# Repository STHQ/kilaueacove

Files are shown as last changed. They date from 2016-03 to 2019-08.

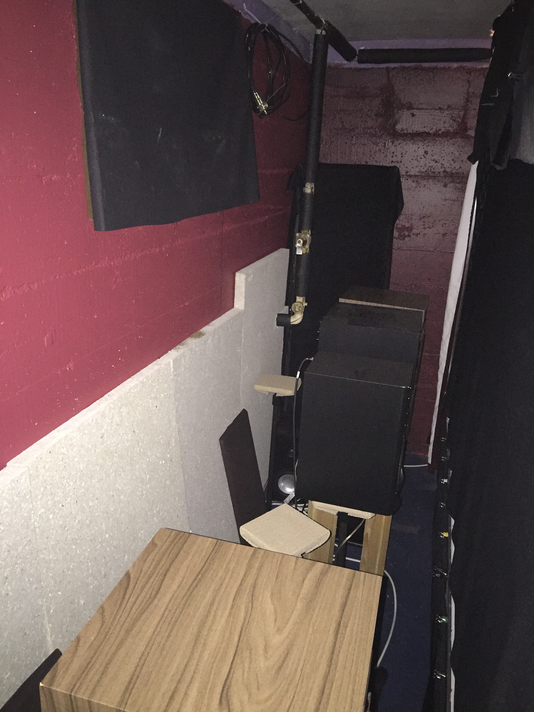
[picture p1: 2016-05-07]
screeningroom/drawings/Screening Room Photos/screening-room-behind-screen.jpg

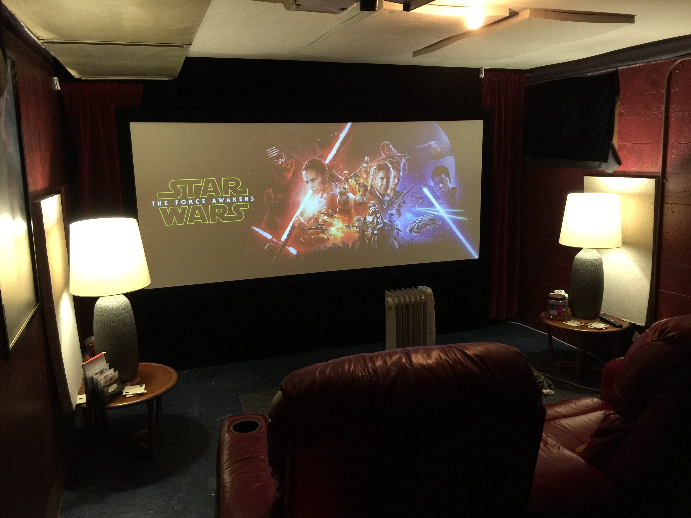
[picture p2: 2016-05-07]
screeningroom/drawings/Screening Room Photos/screening-room-forward.jpg

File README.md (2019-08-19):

# Kilauea Cove

> [As featured on Critiki!](https://news.critiki.com/2017/04/25/how-to-build-a-volcano-raspberry-pi-style/) Thanks, Humuhumu!

This repository relates to my screening room (home theater), the bar area, and the “tiki took,” just outside the screening room’s door, where there is a drinks cart, and shelves with tiki mugs and other barware. Collectively, this is **[Kilauea Cove](https://critiki.com/location/kilauea-cove-seattle-1005/)**.

The purpose is to collect all of my code, wiring diagrams, graphical elements, and setup instructions for the lighting, effects, and other electronics in the space — not only for my own use (if/when we move and I have to piece it back together again), but as a reference for anyone else who plans to build interactive lights and effects for a small space.

I did a [full write-up on my Vixen Labs website](https://vixenlabs.com/2017/02/18/kilauea-cove-raspberry-pi-active-volcano/), with information about how I built the whole Cove space. I have also posted work-in-progress photos and commentary to a thread on [Tiki Central](http://www.tikiroom.com/tikicentral/bb/viewtopic.php?topic=51211&forum=20&25), though that is a bit out of date.

As I update further versions of this project, you'll find posts under the [Kilauea Cove](https://vixenlabs.com/project/kilauea-cove/) tag on Vixen Labs.

## Wiki

[Visit the wiki](https://github.com/bobtiki/kilaueacove/wiki) for more details on construction, programming, and decor!

## The Name

**Q:** Why “Kilauea Cove”?

**A:** The most direct references are [Kilauea](https://en.wikipedia.org/wiki/Kīlauea), the most active volcano in the Hawaiian Islands, which ties in to what I hope will be a very active Volcano Show. *Cove* can be defined as “[a recessed place](http://www.merriam-webster.com/dictionary/cove),” which describes the Tiki Nook very well. Of course, the alternate water-related meaning of *cove*, and the reference to [one of my favorite surf rock bands](http://www.kilaueas.de), only add to the enjoyment.

Plus, y’know, alliteration is pretty fun.

**Q:** Wasn't this called “Lava Lounge” before?

**A:** Yes. However, the old name, “Lava Lounge,” unintentionally duplicated the name of [a Seattle bar](https://critiki.com/location/lava-lounge-seattle-173/). To reduce possible confusion (since I am *also* in Seattle), and to give my space a unique\* name globally, *Kilauea Cove* is the new name.

<sub>\*The only other Kilauea Cove I could find, by searching online, is the name of a pair of water slides at [Big Surf Water Park](http://bigsurffun.com/rides/) in Tempe, AZ.</sub>

## Licenses

The Kilauea Cove project is Copyright © 2016–2018 Mark N. Boszko.

This repository contains clones of software developed by other people, when necessary to the operation of my systems. Their licenses continue to apply.

Unless otherwise stated, all content authored by me, Mark Boszko, and contained in this repository, is covered under one of two permissive licenses — one for software, and one for other elements.

### Software

Since [Creative Commons recommends against applying their licenses to software](https://creativecommons.org/faq/#can-i-apply-a-creative-commons-license-to-software), my code is available under the **MIT license**. This includes code for running on Raspberry Pi and Arduino. Please see [LICENSE.txt](LICENSE.txt) for the full license text, but the rough version is: do what you like with it, but please credit me if you use my code.

### Graphics

Kilauea Cove™ logos and insignia are © 2016–2018 Mark Boszko, and are presented for illustrative purposes. These graphics may not be used without permission.

### Other Elements

All other elements (unless otherwise noted), including documentation, and diagrams, are licensed under **CC-BY-4.0**.

<br /><span xmlns:dct="http://purl.org/dc/terms/" property="dct:title">Kilauea Cove</span> by <a xmlns:cc="http://creativecommons.org/ns#" href="http://stationinthemetro.com/tag/lava-lounge" property="cc:attributionName" rel="cc:attributionURL">Mark N. Boszko</a> is licensed under a <a rel="license" href="http://creativecommons.org/licenses/by/4.0/">Creative Commons Attribution 4.0 International License</a>.

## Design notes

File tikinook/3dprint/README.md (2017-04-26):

# 3D Printer Files

## Kilauea Smoke Mount

v04

This is a 3D-printable mount for a smoke generator, made to fit inside a tiki mug. The mount was designed in [OpenSCAD](http://www.openscad.org), and included here are the current OpenSCAD file (for editing) and Stereo Lithography (STL) file for printing, as well as an image preview render.

### Compatibility

- [Seuthe #5 smoke generator](http://www.gaugemaster.com/item_details.asp?code=SEUTHE%20NO5&r=1) (for model trains / buildings, 4.5-6V, 260mA)
- Trader Sam's Enchanted Tiki Bar, [Krakatoa mug](http://www.ooga-mooga.com/cgi-bin/all/mug.cgi?mode=view&mug_id=7021)
- [NeoPixel Ring - 24 x 5050 RGB LED with Integrated Drivers](https://www.adafruit.com/product/1586)

### Concept
Mount to hold the smoke generator upright inside the base of the tiki mug, with a NeoPixel (LED) ring mount at the top.

### TODO

- Add a ring at the top that I can mount the NeoPixels LED ring to directly

### Version History

- v04
    - Remove “smoke collection hat” that did more harm than good.
    - Left the stems that supported the hat, as a makeshift handle to seat/remove the stand inside the mug.
- v03
    - Added a second small ring to hold the smoke generator more securely and keep it from tipping.
- v02
    - Added smoke “hat”. The idea was to spread the smoke out over a wider area to give the illusion of a larger smoke source. This did not work.
- v01
    - Base ring and small ring for generator only.

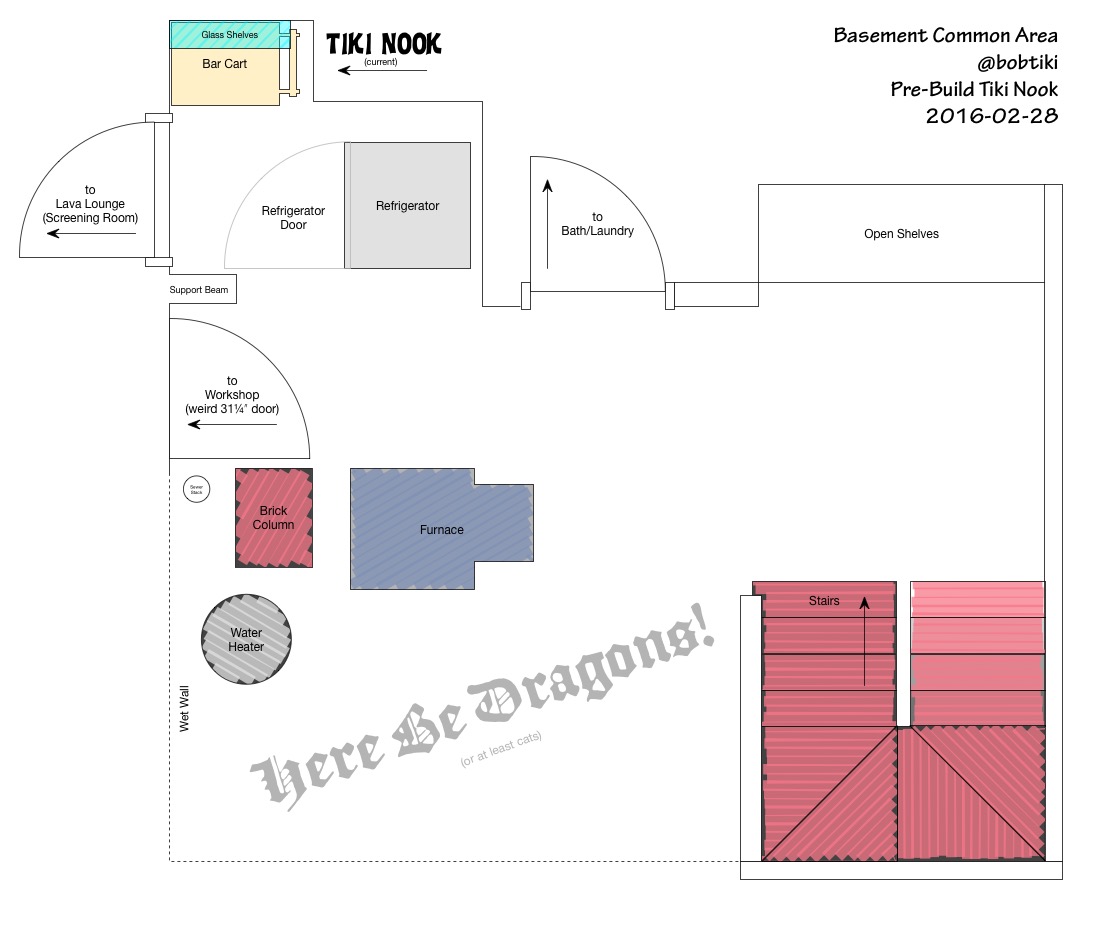
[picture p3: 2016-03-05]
tikinook/drawings/Tiki Nook Overhead.jpg

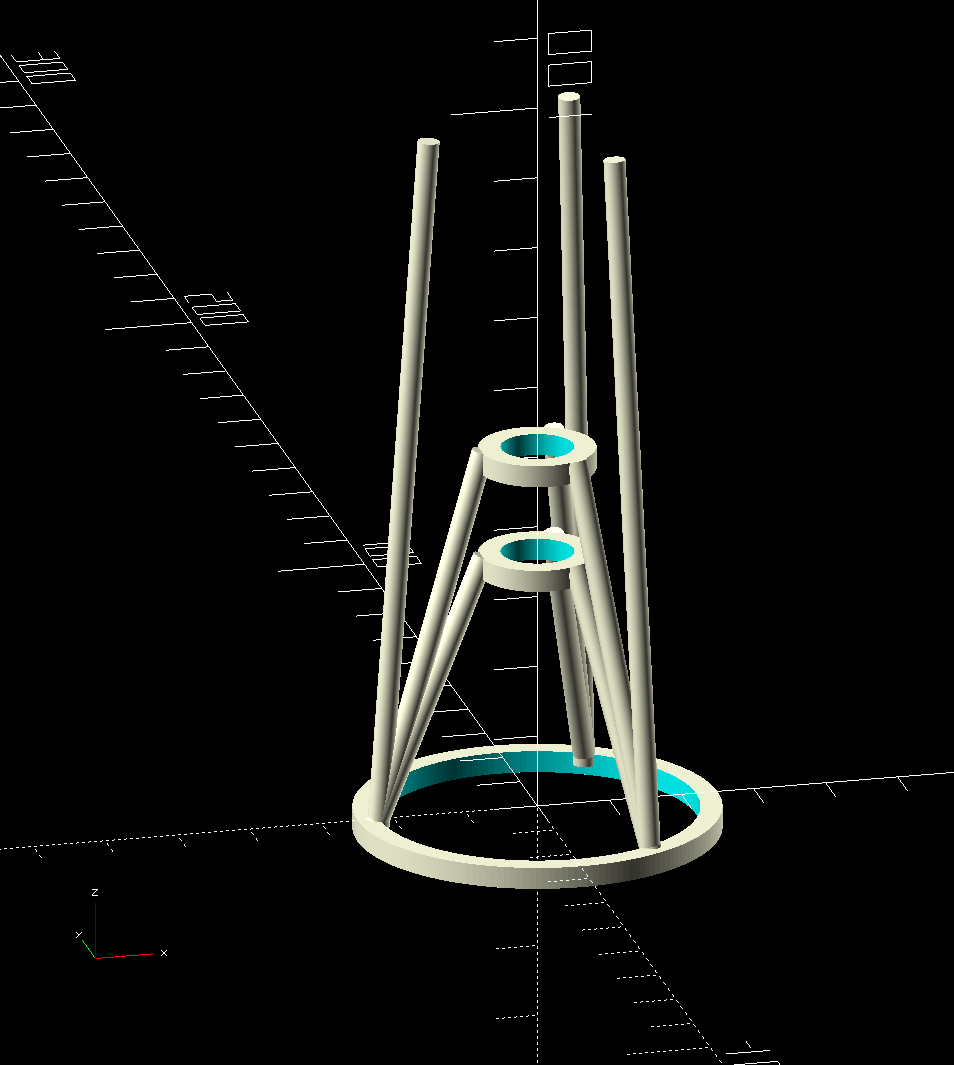
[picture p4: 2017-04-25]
tikinook/3dprint/kilauea-smoke-mount-preview.png

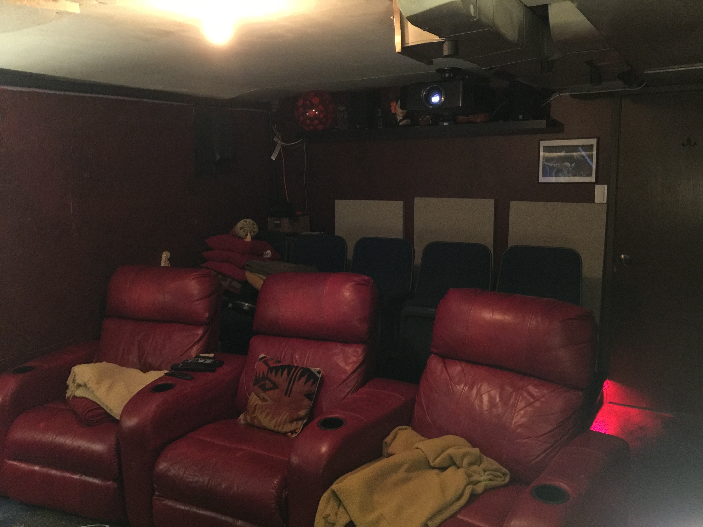
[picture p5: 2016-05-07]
screeningroom/drawings/Screening Room Photos/screening-room-reverse.jpg

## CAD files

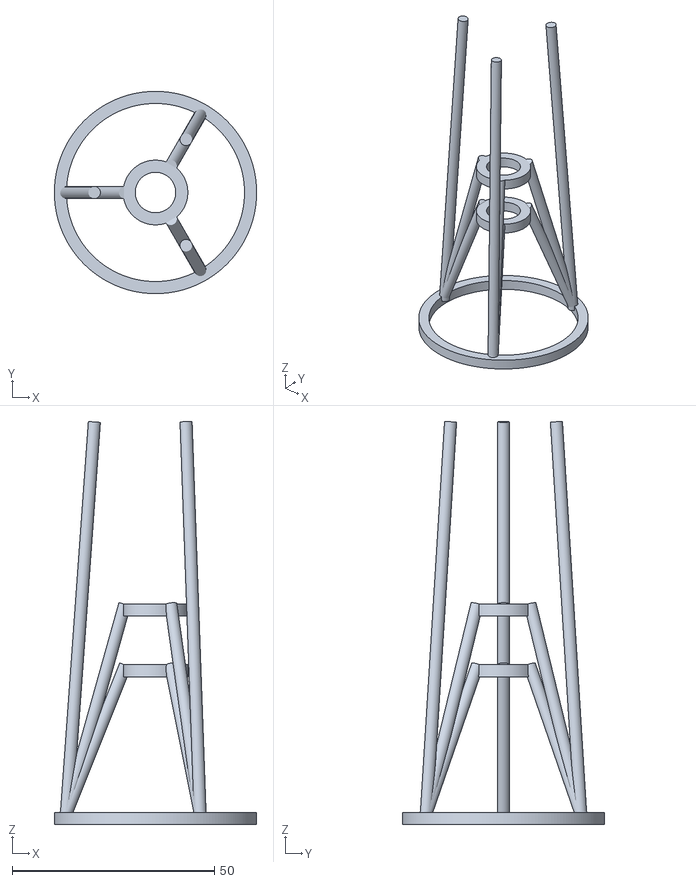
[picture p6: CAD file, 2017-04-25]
tikinook/3dprint/kilauea-smoke-mount.stl
50.0 x 50.0 x 99.6

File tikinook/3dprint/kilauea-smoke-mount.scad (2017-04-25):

// Kilauea Cove
// (c) 2016 Mark Boszko
// Mount for Seuthe smoke generator inside volcano
// v04

// Compatibility:
// - Seuthe #5 smoke generator (for model trains / buildings, 4.5-6V, 260mA)
// - Trader Sam's Enchanted Tiki Bar - Krakatoa mug

// Concept:
// Mount to hold the smoke generator upright in the base of the tiki mug,
// with a separate ring-light mount and smoke collection cone that will(?)
// make the amount of smoke look larger by creating a cylinder of smoke.

// TODO:
// - Add a ring at the top that I can mount the NeoPixels LED ring to directly

// Resolution
// REZ: $fn fragments per circle
//     default: 0 (draft); export: 100 or more
REZ = 180;

// Smoke generator dimensions
gen_diameter = 10.0;  // in mm
gen_height = 45.0;

gen_distance = 50.0;  // distance from base to holder ring
gen_distance_2 = 35.0;
base_diameter = 50.0;

thickness = 3.0;
stems_count = 3;

hat_distance = gen_height + gen_distance + thickness;  // distance from base to smoke collection hat
hat_diameter = 30.0;  // in mm
hat_slope = 2.0;      // ratio of radius to height, x:1


module base() {
    
    base_inner_diameter = base_diameter - thickness * 2;
    
    // the ring itself
    translate([0, 0, - thickness / 2]) difference() {
        cylinder($fn = REZ, h = thickness, d = base_diameter, center = true);
        cylinder($fn = REZ, h = thickness, d = base_inner_diameter, center = true);
    }

}


module gen_ring(height) {
    
    ring_outer_diameter = gen_diameter + thickness * 2;
    
    // the ring itself
    translate([0, 0, height]) difference() {
        cylinder($fn = REZ, h = thickness, d = ring_outer_diameter, center = true);
        cylinder($fn = REZ, h = thickness, d = gen_diameter, center = true);
    }

}


module stem(height) {
    ring_radius = (gen_diameter + thickness * 2) / 2;
    base_radius = (base_diameter - thickness * 2) / 2;
    stem_triangle_base = base_radius - ring_radius;
    stem_triangle_hypotenuse = sqrt(stem_triangle_base * stem_triangle_base + height * height);
    stem_length = stem_triangle_hypotenuse + thickness * 2;
    stem_angle = 90.0 - asin( height / stem_triangle_hypotenuse );
    translate([-base_radius, 0, 0]) rotate([0, stem_angle, 0]) translate([0, 0, -thickness * 1.5]) cylinder($fn = REZ, h = stem_length, d = thickness, center = false);
}

module stems(height) {
    difference() {
        for (i = [1:stems_count]) {
            angle_delta = 360.0 / stems_count;
            angle = i * angle_delta;
            rotate([0, 0, angle]) stem(height);
        }
        // cleanup where the stems stick out of the rings
        translate([0, 0, height + thickness / 2]) cylinder($fn = REZ, h = thickness * 2, d = gen_diameter, center = true);
        translate([0, 0, -thickness * 1.5]) cylinder($fn = REZ, h = thickness * 2, d = base_diameter + thickness, center = true);
    }   
}

// TODO: Convert this into a printed ring to secure the NeoPixel LED ring to
module hat() {
    height = hat_diameter / 2.0 / hat_slope;
    difference() {
        translate([0, 0, hat_distance]) cylinder(h=height, d1=hat_diameter, d2=0, center=true);translate([0, 0, hat_distance - thickness / 3]) cylinder(h=height, d1=hat_diameter, d2=0, center=true);
    }
}

// TODO: modify this for the hat
module hat_stem() {
    hat_radius = (hat_diameter) / 2;
    base_radius = (base_diameter - thickness * 2) / 2;
    stem_triangle_base = base_radius - hat_radius;
    stem_triangle_hypotenuse = sqrt(stem_triangle_base * stem_triangle_base + hat_distance * hat_distance);
    stem_length = stem_triangle_hypotenuse + thickness;
    stem_angle = 90.0 - asin( hat_distance / stem_triangle_hypotenuse );
    translate([-base_radius, 0, 0]) rotate([0, stem_angle, 0]) translate([0, 0, -thickness * 1.5]) cylinder($fn = REZ, h = stem_length, d = thickness, center = false);
}

module hat_stems() {
    difference() {
        for (i = [1:stems_count]) {
            angle_delta = 360.0 / stems_count;
            angle = i * angle_delta;
            rotate([0, 0, angle]) hat_stem();
        }
        // cleanup where the stems stick out of the rings
        translate([0, 0, gen_distance + thickness / 2]) cylinder($fn = REZ, h = thickness * 2, d = gen_diameter, center = true);
        translate([0, 0, -thickness * 1.5]) cylinder($fn = REZ, h = thickness * 2, d = base_diameter + thickness, center = true);
    }
    
}


module assembly() {
    union() {
        base();
        gen_ring(gen_distance);
        stems(gen_distance);
        gen_ring(gen_distance_2);
        stems(gen_distance_2 );
    }
}

assembly();
// removed hat() because it blocks the smoke too much,
//     but keeping the stems, because they're at least handy for picking up
//     the stand from the narrow inside of the mug
hat_stems();

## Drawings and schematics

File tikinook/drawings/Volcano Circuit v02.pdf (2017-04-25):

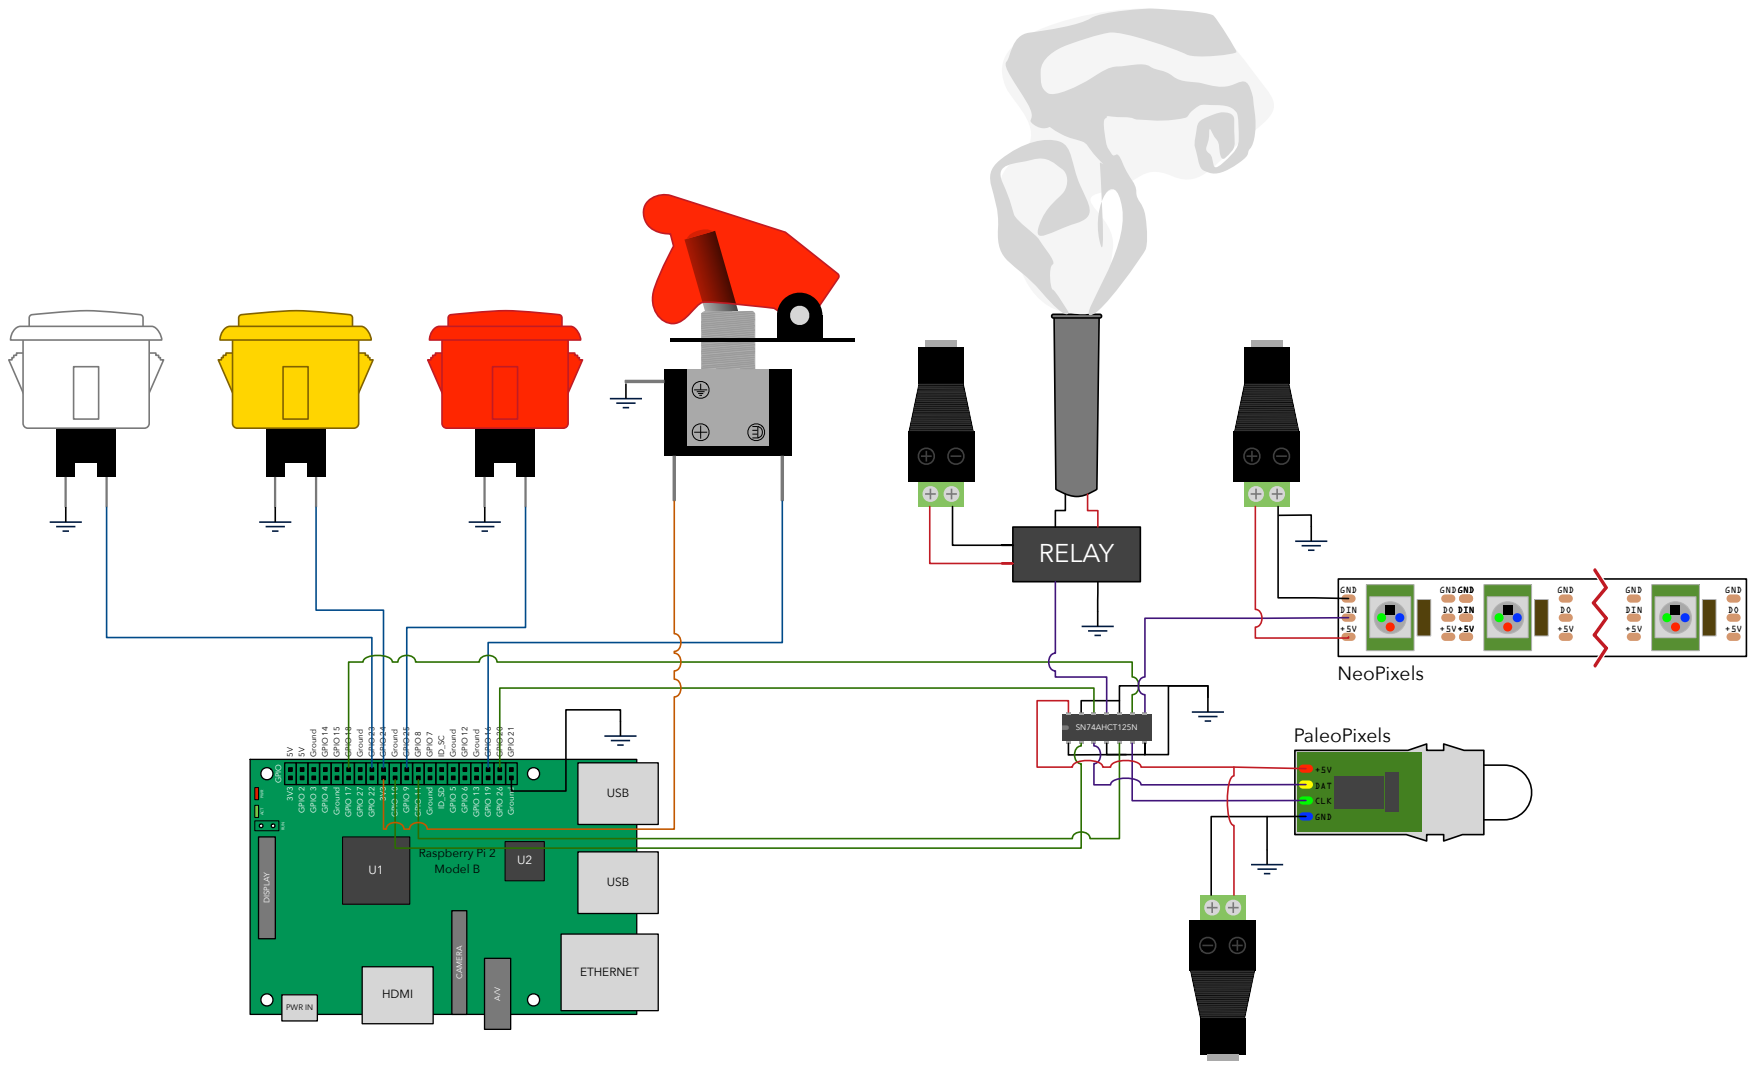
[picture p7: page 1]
ETHERNET; USB; CAMERA; DISPLAY; RUN; ACT PWR; GPIO; GPIO 3; GPIO 11; Ground; GPIO 19; GPIO 2; GPIO 26; GPIO 9; GPIO 17; GPIO 27; GPIO 10; GPIO 4; GPIO 5; GPIO 6; GPIO 22; GPIO 13; GPIO 14; GPIO 15; GPIO 18; GPIO 23; GPIO 24; GPIO 25; GPIO 8; GPIO 7; GPIO 12; GPIO 16; GPIO 20; GPIO 21; Raspberry Pi 2 Model B; GND; DIN; NeoPixels; DAT; CLK; PaleoPixels SN74AHCT125N; RELAY

HDMI PWR IN

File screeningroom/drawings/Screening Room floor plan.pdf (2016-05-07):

L | R C | S

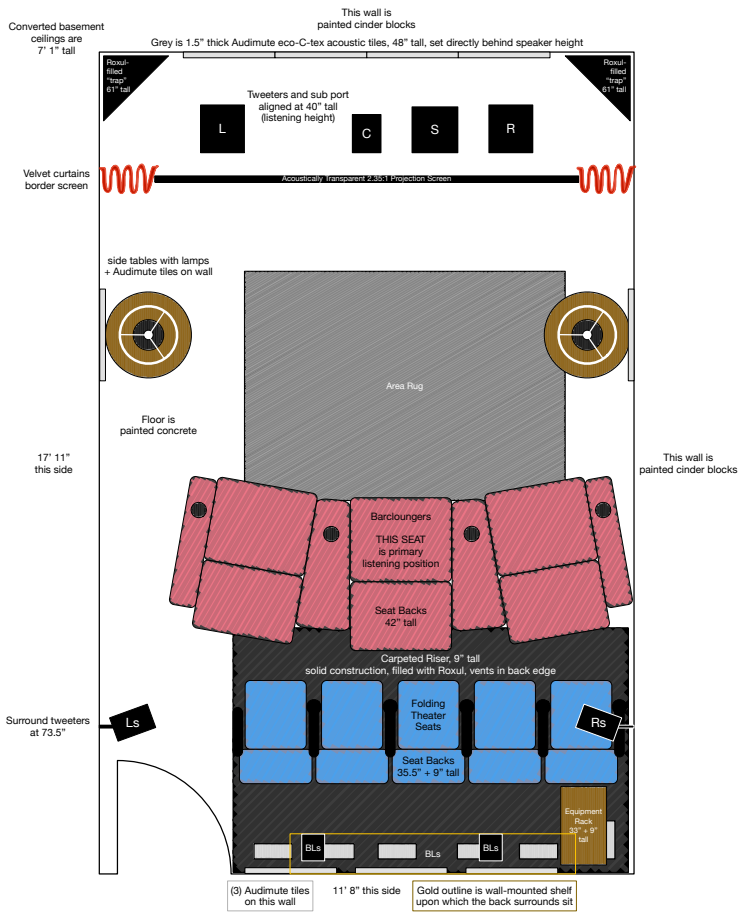
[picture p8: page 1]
Area Rug; Folding Theater Seats; Seat Backs 35.5” + 9” tall; Equipment Rack 33” + 9” tall; Roxul- filled “trap” 61” tall; 11’ 8” this side; 17’ 11” this side; Velvet curtains border screen; Converted basement ceilings are 7’ 1” tall; Floor is painted concrete; Barcloungers; THIS SEAT is primary listening position; Seat Backs 42” tall; Surround tweeters; BLs

This wall is
painted cinder blocks

Grey is 1.5” thick Audimute eco-C-tex acoustic tiles, 48” tall, set directly behind speaker height

Tweeters and sub port
aligned at 40” tall
(listening height)

Acoustically Transparent 2.35:1 Projection Screen

side tables with lamps
+ Audimute tiles on wall

Carpeted Riser, 9” tall

solid construction, filled with Roxul, vents in back edge

(3) Audimute tiles
on this wall

Gold outline is wall-mounted shelf
upon which the back surrounds sit

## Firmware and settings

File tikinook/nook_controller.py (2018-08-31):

#!/usr/bin/env python3
# -*- coding: UTF-8 -*-
"""
Code specific to controlling the lights and other display events
in the tiki nook for Kilauea Cove.

Must be run from the current directory, else the animation will not load, as:
    sudo python nook_controller.py

Author: Mark Boszko (boszko+kilaueacove@gmail.com)

License:
Licensed under The MIT License (MIT). Please see LICENSE.txt for full text
of the license.

Version History:
- 2.0.0 - 2018-08-13 - Upgrades to show, and OSC for communication
- 0.2.0 - 2016-08-07 - Add the 3 button NeoPixels + the 24 ring NeoPixels
                       Fixed the red toggle detection + volcano show restriction
- 0.1.0 - 2016-05-07 - Started development
"""

import argparse
import numpy
import RPi.GPIO as GPIO
import time
import threading

from pythonosc import dispatcher
from pythonosc import osc_server

import neopixel
import paleopixel
from superpixel import *

# ------------------------------
# GPIO setup
# ------------------------------

# Identify GPIO pins

BUTTON_WHITE_IN = 23
BUTTON_AMBER_IN = 24
BUTTON_RED_IN = 25
TOGGLE_RED_IN = 16
SMOKE_CONTROL = 21

# Set up GPIO pins

GPIO.setmode(GPIO.BCM)

GPIO.setup(BUTTON_WHITE_IN, GPIO.IN, pull_up_down=GPIO.PUD_UP)
GPIO.setup(BUTTON_AMBER_IN, GPIO.IN, pull_up_down=GPIO.PUD_UP)
GPIO.setup(BUTTON_RED_IN, GPIO.IN, pull_up_down=GPIO.PUD_UP)
GPIO.setup(TOGGLE_RED_IN, GPIO.IN, pull_up_down=GPIO.PUD_DOWN)
GPIO.setup(SMOKE_CONTROL, GPIO.OUT)

# ------------------------------
# LED setup
# ------------------------------

# Set up the super_strand

# My LED strip configurations (for test):
WHITE_LED = 0  # These are the LEDs inside the buttons
AMBER_LED = 1
RED_LED = 2
NEOPIXEL_COUNT = 271  # Number of NeoPixels in the super_strand
NEOPIXEL_PIN = 18  # GPIO pin connected to the pixels (must support PWM!)
PALEOPIXEL_COUNT = 50  # Number of PaleoPixels in the super_strand

# Create pixel strands with appropriate configuration.
neopixel_strand = neopixel.Adafruit_NeoPixel(NEOPIXEL_COUNT, NEOPIXEL_PIN)
paleopixel_strand = paleopixel.PaleoPixel(PALEOPIXEL_COUNT)

# Combine them into one SuperPixel super_strand
super_strand = SuperPixel(neopixel_strand, paleopixel_strand)

# Intialize the SuperPixel super_strand (must be called once, before other
# functions, if the SuperPixel super_strand contains any NeoPixel sub-strands)
super_strand.begin()

# Set up grid segments
grid = PixelGrid(super_strand, (311, 10), (310, -10), (291, 10), (290, -10), (271, 10), (246, -41), (165, 41), (164, -41),
                 (83, 41), (82, -41), (3, 39))
button_grid = PixelGrid(super_strand, (0, 3))
rattan_grid = PixelGrid(super_strand, (311, 10), (310, -10), (291, 10), (290, -10), (271, 10))
shelf_back_grid = PixelGrid(super_strand, (165, 41), (83, 41), (3, 39))
shelf_front_grid = PixelGrid(super_strand, (246, -41), (164, -41), (82, -41))
ring_grid = PixelGrid(super_strand, (247, 24))


# ------------------------------
# Eruption animation setup
# ------------------------------

# load the animation
volcano_animation = PixelPlayer(rattan_grid, '/home/pi/kilaueacove/tikinook/animation/volcano-v05-16x16.mov')


# ------------------------------
# Globals
# ------------------------------

# Make these globals so threaded button functions can address it
global WHITE_TIMEOUT
WHITE_TIMEOUT = None
# Length in seconds
WHITE_TIMEOUT_LENGTH = 300

global IS_TOGGLE
IS_TOGGLE = False


# ------------------------------
# Callback methods
# ------------------------------

# FIXME: animation functions need to know when another function has been called
#        and cancel any further animation in the current function.

# TODO: smooth transitions between animation functions

# Set up our GPIO callbacks
def button_white(channel='default'):
    """Turns on the bottom row of LEDs white, for mixing drinks.
    
    Times out based on the value in WHITE_TIMEOUT_LENGTH (seconds)
    """
    print("button_white()")
    print("channel: ", channel)

    # Cancel the timer for the white light
    global WHITE_TIMEOUT
    if (WHITE_TIMEOUT is not None):
        WHITE_TIMEOUT.cancel()

    # Set all row colors the same as button_amber(), except
    # get the row underneath the bottom shelf, and show white
    button_grid.setRowColorRGB(0, 16, 16, 16)
    button_grid.setPixelColorRGB(WHITE_LED, 0, 64, 64, 64)
    button_grid.show()
    ring_grid.setRowColorRGB(0, 0, 0, 0)
    ring_grid.show()
    shelf_back_grid.setRowColorRGB(2, 255, 160, 64)  # a more "natural" white
    shelf_back_grid.show()

    # Start a timer to go back to amber after WHITE_TIMEOUT_LENGTH
    WHITE_TIMEOUT = threading.Timer(WHITE_TIMEOUT_LENGTH, button_amber, ['WHITE_TIMEOUT'])
    WHITE_TIMEOUT.start()


def button_amber(channel='default'):
    """Default idle mode.
    
    TODO: subtle animation
    """
    print("button_amber()")
    print("channel: ", channel)

    # Cancel the timer for the white light
    global WHITE_TIMEOUT
    if (WHITE_TIMEOUT is not None):
        WHITE_TIMEOUT.cancel()

    # Set pretty colors
    button_grid.setRowColorRGB(0, 16, 16, 16)
    button_grid.setPixelColorRGB(AMBER_LED, 0, 64, 64, 64)
    button_grid.show()
    ring_grid.setRowColorRGB(0, 0, 0, 0)
    ring_grid.show()
    rattan_grid.setRowColorRGB(0, 250, 127, 0)
    rattan_grid.setRowColorRGB(1, 128, 50, 0)
    rattan_grid.setRowColorRGB(2, 64, 10, 0)
    rattan_grid.setRowColorRGB(3, 0, 90, 75)
    rattan_grid.setRowColorRGB(4, 0, 0, 100)
    shelf_back_grid.setAllColorRGB(0, 2, 4)
    shelf_front_grid.setAllColorRGB(50, 20, 10)
    rattan_grid.show()
    shelf_back_grid.show()
    shelf_front_grid.show()


def toggle_red_on(channel='default'):
    """Volcano Safety Toggle: ON
    
    When on, volcano show can be started by pressing red button.
    """
    print("toggle_red_on")
    print("channel: ", channel)
    global IS_TOGGLE
    IS_TOGGLE = True
    GPIO.remove_event_detect(TOGGLE_RED_IN)
    GPIO.add_event_detect(TOGGLE_RED_IN, GPIO.FALLING, callback=toggle_red_off, bouncetime=300)


def toggle_red_off(channel='default'):
    """Volcano Safety Toggle: OFF
    
    When off, volcano show cannot be started, unless triggered by OSC.
    """
    print("toggle_red_off")
    print("channel: ", channel)
    global IS_TOGGLE
    IS_TOGGLE = False
    GPIO.remove_event_detect(TOGGLE_RED_IN)
    GPIO.add_event_detect(TOGGLE_RED_IN, GPIO.RISING, callback=toggle_red_on, bouncetime=300)


def button_red(channel='default'):
    """Volcano Show
    
    Requires Volcano Safety Toggle to be on.
    Starts a synchronized light, sound, and smoke show.
    TODO: final lighting sequence
    TODO: Sound
    TODO: Smoke
    """
    print("button_red")
    print("channel: ", channel)
    # Does nothing unless the toggle is on
    global IS_TOGGLE
    print("IS_TOGGLE: ", IS_TOGGLE)
    if (IS_TOGGLE):
        # Cancel the timer for the white light, so it doesn't interrupt the show
        global WHITE_TIMEOUT
        if (WHITE_TIMEOUT is not None):
            WHITE_TIMEOUT.cancel()

        # This (should) prevent another volcano run
        #     until the toggle is physically cycled first
        IS_TOGGLE = False

        # Start the show; set color of control box buttons
        button_grid.setRowColorRGB(0, 16, 16, 16)
        button_grid.setPixelColorRGB(RED_LED, 0, 64, 64, 64)
        button_grid.show()

        # TODO: Slower fade out, bottom to top
        # Blackout
        # grid.setAllColorRGB(0, 0, 0)
        # grid.show()
        pixel_count = len(super_strand.getPixels())
        new_colors = numpy.zeros((pixel_count, 3), dtype=numpy.int)
        super_strand.fade_to_colors(new_colors=new_colors, seconds=3)

        # Smoke starts
        GPIO.output(SMOKE_CONTROL, GPIO.HIGH)

        # TODO, top row slower shrink in from edges, turn red
        # Highlight the volcano
        y = 0  # top row
        shelf_front_grid.setAllColorRGB(0, 0, 0)
        shelf_front_grid.setPixelColorRGB(20, y, 255, 0, 0)
        shelf_front_grid.show()
        shelf_back_grid.setRowColorRGB(0, 4, 0, 0)
        shelf_back_grid.show()
        time.sleep(0.01)
        shelf_front_grid.setPixelColorRGB(19, y, 125, 0, 0)
        shelf_front_grid.setPixelColorRGB(21, y, 128, 0, 0)
        shelf_front_grid.show()
        shelf_back_grid.setRowColorRGB(0, 16, 0, 0)
        shelf_back_grid.setRowColorRGB(1, 4, 0, 0)
        shelf_back_grid.show()
        time.sleep(0.01)
        shelf_front_grid.setPixelColorRGB(18, y, 64, 0, 0)
        shelf_front_grid.setPixelColorRGB(22, y, 64, 0, 0)
        shelf_front_grid.show()
        shelf_back_grid.setRowColorRGB(0, 64, 0, 0)
        shelf_back_grid.setRowColorRGB(1, 16, 0, 0)
        shelf_back_grid.setRowColorRGB(2, 4, 0, 0)
        shelf_back_grid.show()
        time.sleep(10)

        # Turn the ring red to highlight smoke
        # TODO: make this fluctuate red/orage/yellow during eruption sequence
        ring_grid.setRowColorRGB(0, 255, 0, 0)
        ring_grid.show()
        time.sleep(4)

        # Play animation
        # FIXME: Slow this down!
        volcano_animation.play(delay=0.013)

        # Smoke off
        GPIO.output(SMOKE_CONTROL, GPIO.LOW)
        time.sleep(3)

        # Fade to black
        new_colors = numpy.zeros((pixel_count, 3), dtype=numpy.int)
        super_strand.fade_to_colors(new_colors=new_colors, seconds=1)
        time.sleep(3)

        # Fade up to Amber
        # Start with black
        amber_colors = numpy.zeros((pixel_count, 3), dtype=numpy.int)
        # Assign Amber colors
        amber_colors[WHITE_LED] = [16, 16, 16]
        amber_colors[AMBER_LED] = [64, 64, 64]
        amber_colors[RED_LED] = [16, 16, 16]
        # Ring is already black, no need to change
        for index in range(311, 321):
            # Rattan row 0
            amber_colors[index] = [250, 127, 0]
        for index in range(301, 311):
            # Rattan row 1
            amber_colors[index] = [128, 50, 0]
        for index in range(291, 301):
            # Rattan row 2
            amber_colors[index] = [64, 10, 0]
        for index in range(281, 291):
            # Rattan row 3
            amber_colors[index] = [0, 90, 75]
        for index in range(271, 281):
            # Rattan row 4
            amber_colors[index] = [0, 0, 100]
        for index in range(165, 206):
            # Shelf Back row 0
            amber_colors[index] = [0, 2, 4]
        for index in range(83, 124):
            # Shelf Back row 1
            amber_colors[index] = [0, 2, 4]
        for index in range(3, 42):
            # Shelf Back row 2
            amber_colors[index] = [0, 2, 4]
        for index in range(206, 247):
            # Shelf Front row 0
            amber_colors[index] = [50, 20, 10]
        for index in range(124, 165):
            # Shelf Front row 1
            amber_colors[index] = [50, 20, 10]
        for index in range(42, 83):
            # Shelf Front row 2
            amber_colors[index] = [50, 20, 10]

        # Fade
        super_strand.fade_to_colors(new_colors=amber_colors, seconds=2)

        # Comment out so I can examine the fade results
        button_amber(channel='volcano_end')


def erupt_handler(unused_addr, args, erupt):
    # erupt == 1.0 always, so I'm not even going to check
    print("erupt_handler()")
    print("unused_addr:", unused_addr)
    print("args:", args)
    print("erupt:", erupt)
    global IS_TOGGLE
    IS_TOGGLE = True
    button_red(channel='OSC')


# ------------------------------
# Main code
# ------------------------------

if __name__ == "__main__":
    # Set up OSC variables from command line args
    parser = argparse.ArgumentParser()
    parser.add_argument("--ip", default="192.168.10.15", help="The ip to listen on")
    parser.add_argument("--port", type=int, default=8000, help="The port to listen on")
    args = parser.parse_args()

    # Initialize physical button interrupts
    GPIO.add_event_detect(TOGGLE_RED_IN, GPIO.RISING, callback=toggle_red_on, bouncetime=500)
    GPIO.add_event_detect(BUTTON_WHITE_IN, GPIO.FALLING, callback=button_white, bouncetime=500)
    GPIO.add_event_detect(BUTTON_AMBER_IN, GPIO.FALLING, callback=button_amber, bouncetime=500)
    GPIO.add_event_detect(BUTTON_RED_IN, GPIO.FALLING, callback=button_red, bouncetime=500)

    # Display the default pattern once
    button_amber()

    # Set up the OSC listener
    dispatcher = dispatcher.Dispatcher()
    dispatcher.map("/erupt", erupt_handler, "Erupt")
    # Run the server on its own thread
    server = osc_server.ForkingOSCUDPServer((args.ip, args.port), dispatcher)
    server_thread = threading.Thread(target=server.serve_forever)
    server_thread.start()
    print("OSC listening on {}".format(server.server_address))

    # Idle loop
    try:
        while True:
            time.sleep(1)
    except KeyboardInterrupt:
        print("\nAttempting to clean up…")
    finally:
        server.shutdown()
        GPIO.cleanup()

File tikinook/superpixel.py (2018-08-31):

#!/usr/bin/env python
# -*- coding: UTF-8 -*-

import time

import cv2
import numpy
import subprocess

import neopixel
import paleopixel

# SuperPixel
# Author:  Mark Boszko
#
# Combines both NeoPixels and PaleoPixels (WS2801) into a single addressable
# SuperPixel type. Also allows merging of separate pixel strands into one
# master strand or grid.


# My LED strip configurations (for test):
NEOPIXEL_COUNT = 271  # Number of NeoPixels in the strand
NEOPIXEL_PIN = 18  # GPIO pin connected to the pixels (must support PWM!)
PALEOPIXEL_COUNT = 50  # Number of PaleoPixels in the strand

# My grid configuration (for test):
TIKI_NOOK_GRID = [(311, 10), (310, -10), (291, 10), (290, -10), (271, 10),
                  (247, 24),
                  (246, -41), (165, 41), (164, -41), (83, 41), (82, -41), (3, 39),
                  (0, 3)]


# Rows, bottom up: 39, -41, 41, -41,  41, -41, -11,  10, -10,  10,  -9
# Index, bottom up: 0,  79, 80, 161, 162, 243, 254, 255, 274, 275, 293

# Fade frames per second
FADE_FPS = 30


#####
#
# SuperPixel - superset pixel strand class
#
#####

# FIXME: We need to make sure that we use the RGB color functions for all pixel
# settings, because NeoPixels and PaleoPixels now use different internal
# color representations.
# PaleoPixel color = [R, G, B] numpy.array
# NeoPixel color = 24-bit color int

def Color(red, green, blue):
    """Return the provided red, green, blue colors as a numpy array.
    Each color component should be a value 0-255 where 0 is the lowest intensity
    and 255 is the highest intensity.
    red, green, blue: int, 0-255
    return: numpy.array
    """
    # "& 0xFF" is to make sure we're not exceeding max setting of 255
    # 2018-08-22 This seems to have an error with Python 3
    # rgb = numpy.array([red & 0xFF, green & 0xFF, blue & 0xFF])
    rgb = numpy.array([red, green, blue])
    return rgb


class SuperPixel(object):
    def __init__(self, *strands):
        """Class to represent a superset of both neopixel and paleopixel strands

        strands - Variable argument list of sub-strands which should make up
                  the one SuperPixel strand. The sub-strands are added to the
                  super-strand in the order the arguments are listed.
        """
        self._strands = strands
        pixel_count = 0
        for strand in self._strands:
            pixel_count = pixel_count + strand.numPixels()

        # Create an array for all of the LED color data:
        # 2D numpyarray, LED count by 3 (RGB), type int
        self._led_data = numpy.zeros((pixel_count, 3), dtype=numpy.int)

    def __del__(self):
        # Clean up memory used by the library when not needed anymore.
        if self._led_data is not None:
            self._led_data = None
        if self._strands is not None:
            self._strands = None

    def begin(self):
        """Initialize _led_data to zeroes and set up NeoPixels
        """
        for strand in self._strands:
            strand.begin()
        self.show()

    def show(self):
        """Update the display with the data from the LED buffer."""
        for strand in self._strands:
            # Each strand knows how to show itself.
            strand.show()

    def setPixelColor(self, n, color_rgb):
        """Set LED at position n to the provided numpy array [R, G, B].
        n: int
        color: numpy.array, as [R, G, B]
        """
        if (n >= len(self._led_data)):
            return  # pixel 'n' is out of bounds; throw it away

        # SuperPixel internal representation:
        self._led_data[n] = color_rgb

        # Now also set it in the sub-strand
        pixel_offset = 0
        pixel_max = 0
        for strand in self._strands:
            # Determine which strand this pixel is a part of, and set it.
            pixel_max = pixel_offset + strand.numPixels()
            if (pixel_offset <= n) and (n < pixel_max):
                pixel = n - pixel_offset
                strand.setPixelColorRGB(pixel, color_rgb[0].item(), color_rgb[1].item(), color_rgb[2].item())
                break
            else:  # Must be in the next one
                pixel_offset = pixel_offset + strand.numPixels()

    def setPixelColorRGB(self, n, red, green, blue):
        """Set LED at position n to the provided red, green, and blue color.
        Each color component should be a value from 0 to 255 (where 0 is the
        lowest intensity and 255 is the highest intensity).
        n: int, pixel location
        red, green, blue: int, 0-255
        """
        self.setPixelColor(n, Color(red, green, blue))
        # self.setPixelColor(n, red, green, blue)

    def getPixels(self):
        """Return an object which allows access to the LED display data as if
        it were a sequence of 24-bit RGB values.
        """
        return self._led_data

    def numPixels(self):
        """Return the number of pixels in the display."""
        return len(self._led_data)

    def getPixelColor(self, n):
        """Get the [R, G, B] color array for the LED at position n.
        n: int
        """
        return self._led_data[n]

    def fade_to_colors(self, new_colors, seconds):
        """Fade from the current pixel colors to a new list of
        pixel color values, over a float number of seconds.
        """
        frame_delay = 1.0 / FADE_FPS
        # print("frame_delay", frame_delay)
        frames = int(FADE_FPS * seconds)
        # print("frames", frames)
        for frame in range(frames):
            frames_remain = frames - frame
            current_colors = self._led_data
            for index, current_rgb in enumerate(current_colors):
                new_rgb = []
                for color in range(3):
                    delta = current_rgb[color] - new_colors[index][color]
                    if delta != 0 and frames_remain != 0:
                        delta_frame = int(delta / frames_remain)
                        new_rgb.append(current_rgb[color] - delta_frame)
                    else:
                        new_rgb.append(current_rgb[color])
                self.setPixelColor(index, new_rgb)
            self.show()
            # time.sleep(frame_delay)


#####
#
# PixelGrid
#
#####
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

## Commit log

2016-02-29 First commit
    Choosing licenses. Initial framework.
2016-03-01 First commit
    FIXME: Does not actually make the SuperPixel type yet. This is just for
    testing.
    [superpixel.py]
2016-03-01 First real implementation
    There are probably some bugs. Let’s find them!
    [superpixel.py]
2016-03-01 Revert "test"
    This reverts commit b3dc35bbfb4f4d60df992bb8b079e12233d5bf18.
    [superpixel.py]
2016-03-01 Revert "Test with both strands"
    This reverts commit 815fbb74a2fccfd0f02ac93e5d34295f617d1638.
    [superpixel.py]
2016-03-01 Revert "Test with another single strand"
    This reverts commit 1ed40bcc58b526203d692381760af9ba38db7a71.
    [superpixel.py]
2016-03-01 Update paleopixel.py to use direct os access to SPI
2016-03-02 Revert "Trying to speed things up by using one os.write() call per pixel"
    This reverts commit 7189abf96ba2c49b0a5223cd5b5fe9abb496b7a5.
    [paleopixel.py]
2016-03-02 debug prints
2016-03-02 more debug prints
2016-03-02 Remove debug prints
2016-03-02 Raised max speed to 2.5 KHz
    WS2801 data sheet: https://www.adafruit.com/datasheets/WS2801.pdf
    says “PWM free-run capability(refresh rate(2.5KHz)”
    but also “Maximum input clock frequency 25MHz”
    so… which one is the one I need to pay attention to? I dunno.
2016-03-02 Writing bytes to SPI on a per-pixel basis
    (I’m assuming waiting to do them all at once is what’s timing out the
    connection)
2016-03-03 fixed x, y confusion, more tests
    [superpixel.py]
2016-03-08 Update superpixel.py — testing
2016-03-27 New idle pattern; temp fix for GRB issue with NeoPixels; tabs to spaces
    [neopixel.py, paleopixel.py, superpixel.py]
2016-05-08 Restored wheel modulo in rainbow tests
2016-05-08 remove append; clean up debug prints
2016-05-08 Base animatoin load on LED grid shape
2016-05-09 cleanup, debug print statements
2016-05-09 GPIO control of PaleoPixels is borked while interrupts are active
2016-05-10 resolved paleopixel issue
    time.sleep(1)
    [nook_controller.py]
2016-05-12 Set up initial test stages and animations
2016-05-15 New button control flow
2016-08-07 Recovered Fritzing diagrams, hopefully
    [Tiki Nook Control - WS2801 Pixels Only.fzz, Tiki Nook Control v01.fzz, Tiki Nook Control v02.fzz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]
2016-08-07 Add button and ring NeoPixels
2016-08-07 Tested strand including button and ring Neopixels
    Adjusted LED numbers to reflect new layout
2016-08-07 created globals for GPIO pin designations
2016-08-07 Switch toggle detect to pull-down
2016-08-08 Enhanced debug prints
2016-08-08 Fixed red toggle detection, restriction on red button
    [nook_controller.py]
2016-08-08 Testing the pins for the power relays
2016-08-09 Added SMOKE_POWER relay control
2016-08-18 GPIO 20 now controls the fish float lamp relay
2016-08-18 Testing smoke control relay
2016-08-20 Revert "First test with audio"
    This reverts commit 1f12e6741b74c85f3943d2ef7c027b4535bba6bb.
    [nook_controller.py]
2016-08-20 Different sound output method
    Using the Adafruit Audio FX Sound Board, http://adafru.it/2220
2017-04-25 Volcano controller circuit diagram
    in both PDF and OmniGraffle formats
2017-04-25 Added 3D-printable mount for smoke generator
    [kilauea-smoke-mount.scad, kilauea-smoke-mount.stl]
2017-04-26 Added info about Kilauea Smoke Mount
2017-08-07 Revert "Trying to use the Hue bridge for light control"
    This reverts commit 80c034d8e9c51b8a3df5ed77611b4e13eaed340d.
    [nook_controller.py]
2017-08-07 Revert "Revert "Trying to use the Hue bridge for light control""
    This reverts commit e2c571bb1ab6448c9ba1533b1c21383d024b9639.
    [nook_controller.py]
2017-08-07 Revert "Revert "Revert "Trying to use the Hue bridge for light control"""
    This reverts commit 82fecb05119b2cc61397365cd8073d98c76046bc.
    [nook_controller.py]
2018-08-14 FIXME: Temporary patch; the colors are all screwed up now
    [paleopixel.py]
2018-08-23 Revert "Making some comments"
    This reverts commit e3b8da96e33ce7220f8f549d30c401819478398c.
    [paleopixel.py]
2018-08-24 Debug print to see what's sent via OSC
2018-08-24 super_strand renamd; run OSC server on seperate thread
2018-08-24 debugging print statements
2018-08-24 different debugging print statements
2018-08-24 Forgot frames loop
2018-08-24 Only show once per frame. Removed delay for testing
2018-08-24 removing print statements
2018-08-24 Slow down the Volcano animation — too fast now!
    [nook_controller.py, superpixel.py]
